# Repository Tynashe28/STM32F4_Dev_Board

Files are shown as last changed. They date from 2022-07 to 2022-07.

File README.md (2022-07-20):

# STM32F4_Dev_Board

This is a STM32f4 development board designed in Autodesk Eagle. It is Based on the High Perfomance STM32f405RGT6 32-Bit Arm Cortex M4 Microcontroller from ST. 

## Pinout
✔ feature 19 pins broken out from the MCU's Port PB, PA & PC. Refer to the Pcb board for the pinout.

### USB
✔ Support usb full speed @12mbps

### Communication Protocols
✔ For I2C, CAN, SPI and USART connections reference the pins from the datasheet, NOT CHANGED.

## POWER
✔ Can be powered by usd or 12v-24 it can also supply 3.3v and 5v to peripheral connections / devices

## DEBUGING AND UPLOADING FIRMWARE
✔ features a switch to select boot mode (Debug / Run) & Debugging is done via USB. Board doesn't have Serial Wire Debug

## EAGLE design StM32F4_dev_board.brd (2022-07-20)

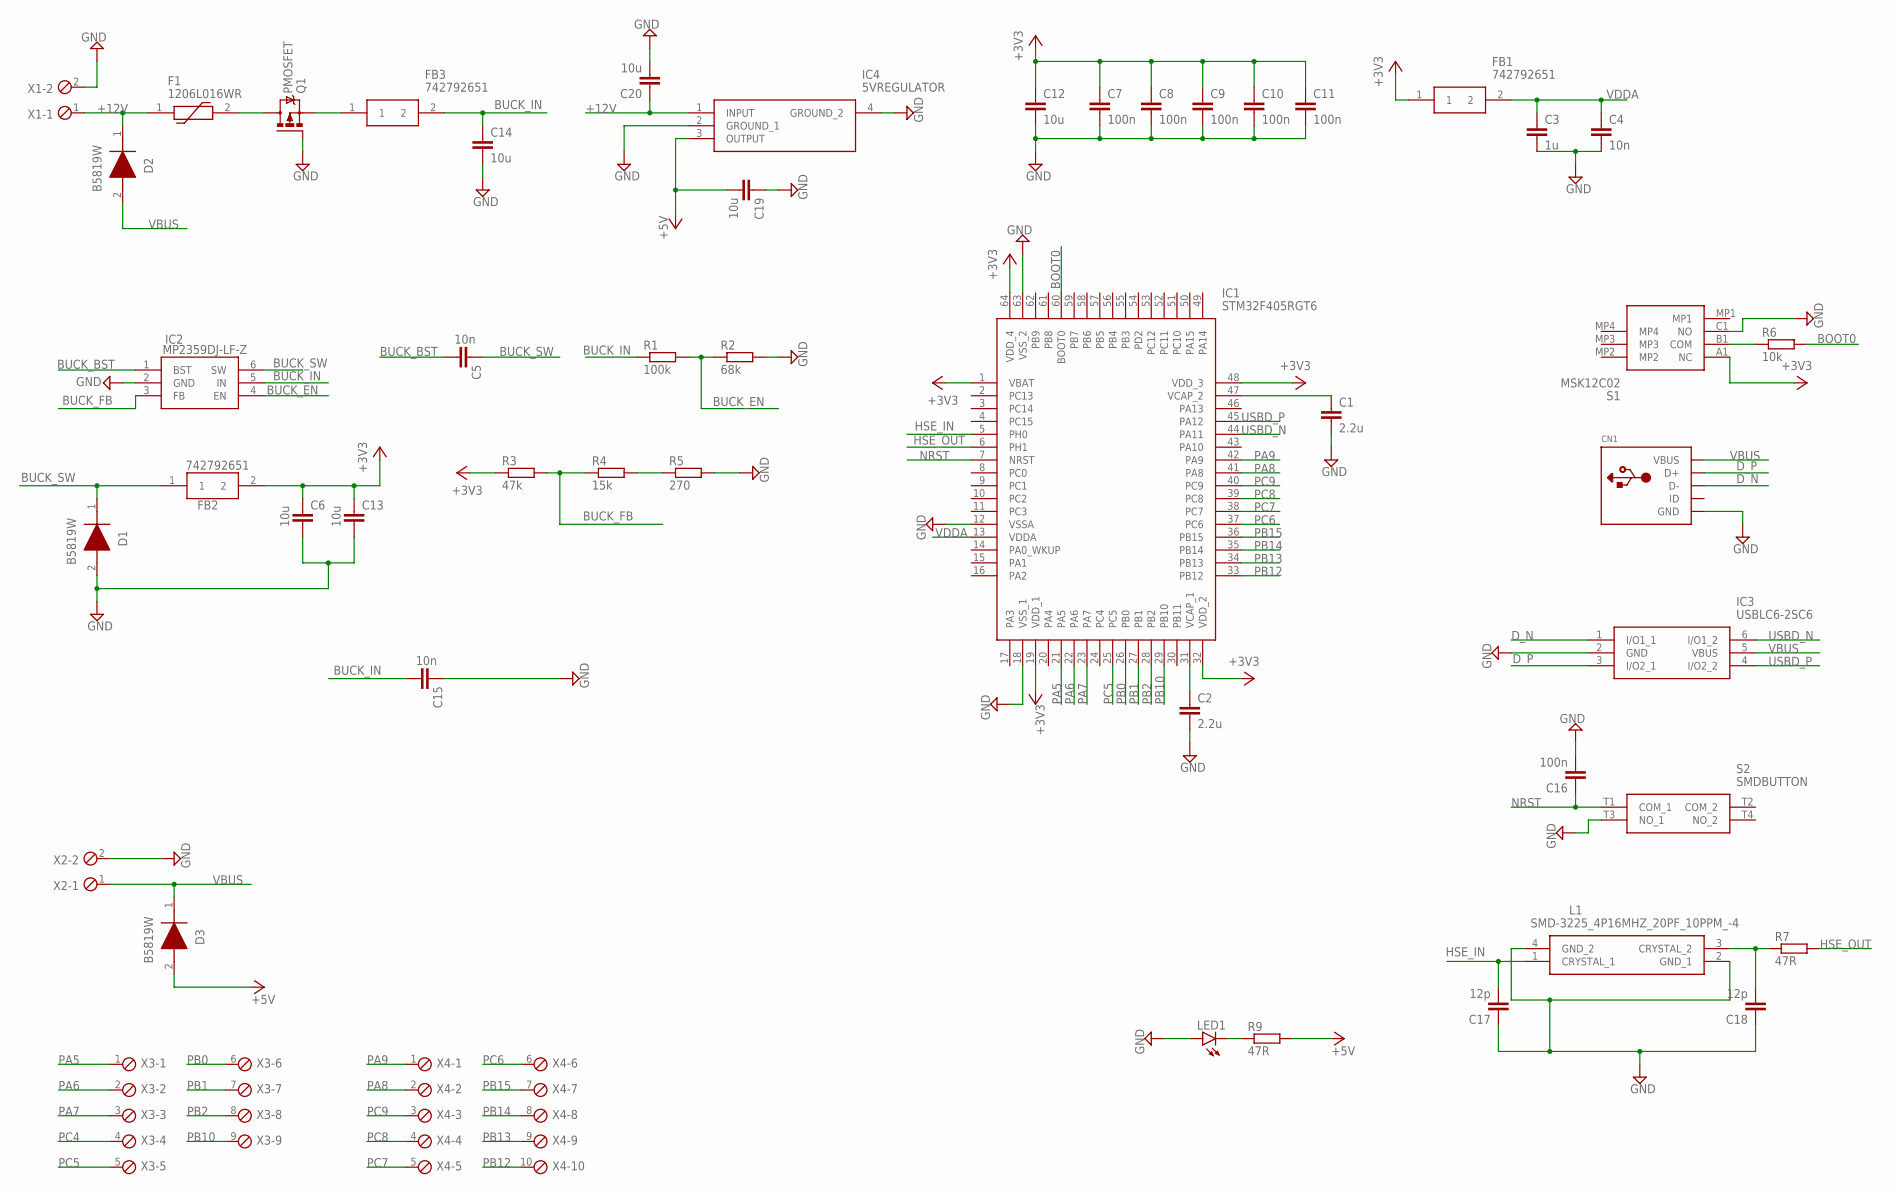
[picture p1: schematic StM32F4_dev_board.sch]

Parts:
C1, C2: 2.2u; C0603
C3: 1u; C0805
C4, C5, C15: 10n; C0805
C6, C12, C13, C14, C19, C20: 10u; C0805
C7, C8, C9, C10, C11: 100n; C0805
C16: 100n; C0603K
C17, C18: 12p; C0603K
CN1: USBMINIB; USB-MINIB
D1, D2, D3: B5819W
F1: 1206L016WR; POLYFUSE1206
FB1, FB2, FB3: 742792651; BEADC1608X100N
IC1: STM32F405RGT6; STM32F405RTG6
IC2: MP2359DJ-LF-Z; MP2359
IC3: USBLC6-2SC6; USBLC6
IC4: 5VREGULATOR; SOT23-5V
L1: SMD-3225_4P16MHZ_20PF_10PPM_-4; SMD3225_4P16MHZ20PF10PPM4085
LED1: LEDCHIP-LED0603; CHIP-LED0603
Q1: PMOSFET; SOT23
R1: 100k; R0805
R2: 68k; R0805
R3: 47k; R0805
R4: 15k; R0805
R5: 270; R0805
R6: 10k; R0603
R7, R9: 47R; R0603
S1: MSK12C02
S2: SMDBUTTON
X1, X2: MPT2; 2POL254
X3: MPT9; 9POL254
X4: MPT10; 10POL254

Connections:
+3V3: C6.1, C7.1, C8.1, C9.1, C10.1, C11.1, C12.1, C13.1, FB1.1, FB2.2, IC1.1 (VBAT), IC1.19 (VDD_1), IC1.32 (VDD_2), IC1.48 (VDD_3), IC1.64 (VDD_4), R3.1, S1.A1 (NC)
+5V: C19.2, D3.2 (A), IC4.3 (OUTPUT), R9.2
+12V: C20.1, D2.1 (K), F1.1, IC4.1 (INPUT), X1.1
BOOT0: IC1.60 (BOOT0), R6.2
BUCK_BST: C5.2, IC2.1 (BST)
BUCK_EN: IC2.4 (EN), R1.2, R2.1
BUCK_FB: IC2.3 (FB), R3.2, R4.1
BUCK_IN: C14.1, C15.2, FB3.2, IC2.5 (IN), R1.1
BUCK_SW: C5.1, D1.1 (K), FB2.1, IC2.6 (SW)
D_N: CN1.D-, IC3.1 (I/O1_1)
D_P: CN1.D+, IC3.3 (I/O2_1)
GND: C1.2, C2.2, C3.2, C4.2, C6.2, C7.2, C8.2, C9.2, C10.2, C11.2, C12.2, C13.2, C14.2, C15.1, C16.2, C17.1, C18.1, C19.1, C20.2, CN1.GND, D1.2 (A), IC1.12 (VSSA), IC1.18 (VSS_1), IC1.63 (VSS_2), IC2.2 (GND), IC3.2 (GND), IC4.2 (GROUND_1), IC4.4 (GROUND_2), L1.2 (GND_1), L1.4 (GND_2), LED1.A, Q1.1 (G), R2.2, R5.2, S1.C1 (NO), S2.T3 (NO_1), X1.2, X2.2
HSE_IN: C17.2, IC1.5 (PH0), L1.1 (CRYSTAL_1)
HSE_OUT: IC1.6 (PH1), R7.2
unnamed: C1.1, IC1.47 (VCAP_2)
unnamed: C2.1, IC1.31 (VCAP_1)
unnamed: LED1.C, R9.1
unnamed: R4.2, R5.1
unnamed: F1.2, Q1.3 (D)
unnamed: FB3.1, Q1.2 (S)
unnamed: R6.1, S1.B1 (COM)
unnamed: C18.2, L1.3 (CRYSTAL_2), R7.1
NRST: C16.1, IC1.7 (NRST), S2.T1 (COM_1)
PA5: IC1.21 (PA5), X3.1
PA6: IC1.22 (PA6), X3.2
PA7: IC1.23 (PA7), X3.3
PA8: IC1.41 (PA8), X4.2
PA9: IC1.42 (PA9), X4.1
PB0: IC1.26 (PB0), X3.6
PB1: IC1.27 (PB1), X3.7
PB2: IC1.28 (PB2), X3.8
PB10: IC1.29 (PB10), X3.9
PB12: IC1.33 (PB12), X4.10
PB13: IC1.34 (PB13), X4.9
PB14: IC1.35 (PB14), X4.8
PB15: IC1.36 (PB15), X4.7
PC4: X3.4
PC5: IC1.25 (PC5), X3.5
PC6: IC1.37 (PC6), X4.6
PC7: IC1.38 (PC7), X4.5
PC8: IC1.39 (PC8), X4.4
PC9: IC1.40 (PC9), X4.3
USBD_N: IC1.44 (PA11), IC3.6 (I/O1_2)
USBD_P: IC1.45 (PA12), IC3.4 (I/O2_2)
VBUS: CN1.VBUS, D2.2 (A), D3.1 (K), IC3.5 (VBUS), X2.1
VDDA: C3.1, C4.1, FB1.2, IC1.13 (VDDA)

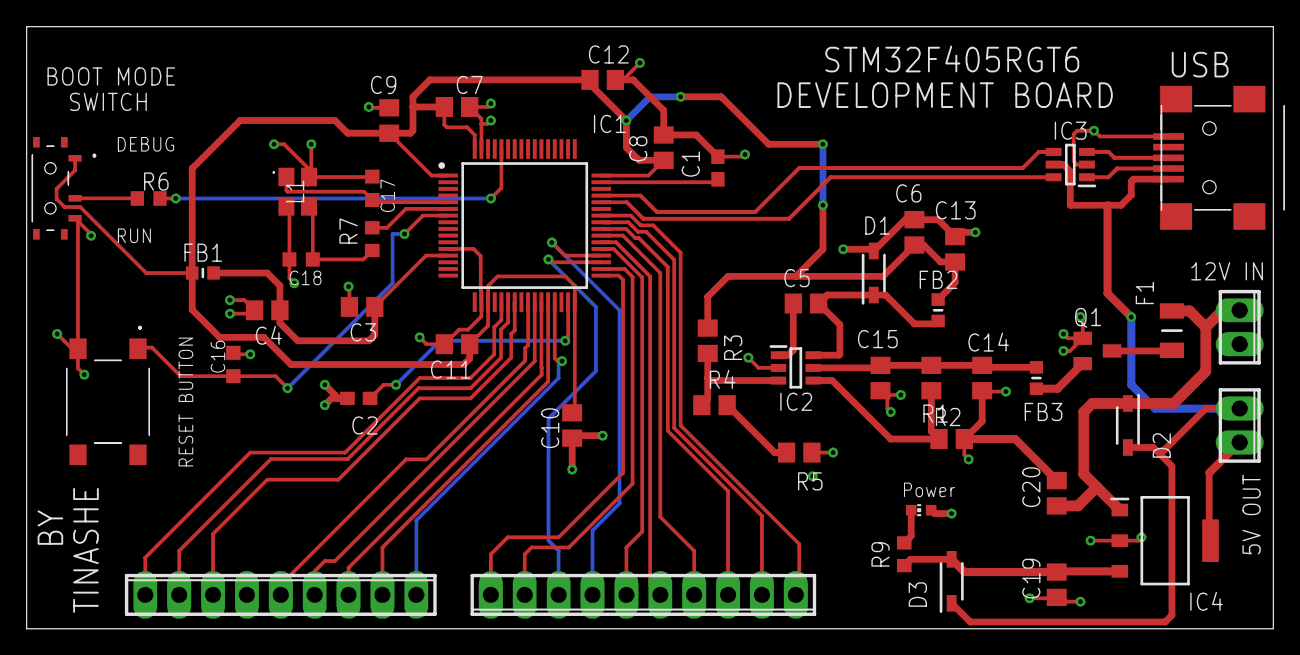
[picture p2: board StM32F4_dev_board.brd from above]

Board: 2 copper layers, 93.5 x 45.1 mm, 49 parts (0 on the bottom side), 45 nets.
